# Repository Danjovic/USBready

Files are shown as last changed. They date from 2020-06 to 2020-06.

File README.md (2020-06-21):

# USBready
USB breadboard ready development board

Uses [USBaspLoader](https://www.obdev.at/products/vusb/usbasploader.html) as a bootloader. 

Precompiled .hex files available on 
[repository ](/Firmware/Bootloader/USBaspLoader.2012-12-08/hexfiles/)

PCB shared at [OSHPark](https://oshpark.com/shared_projects/ElsYFBDc)

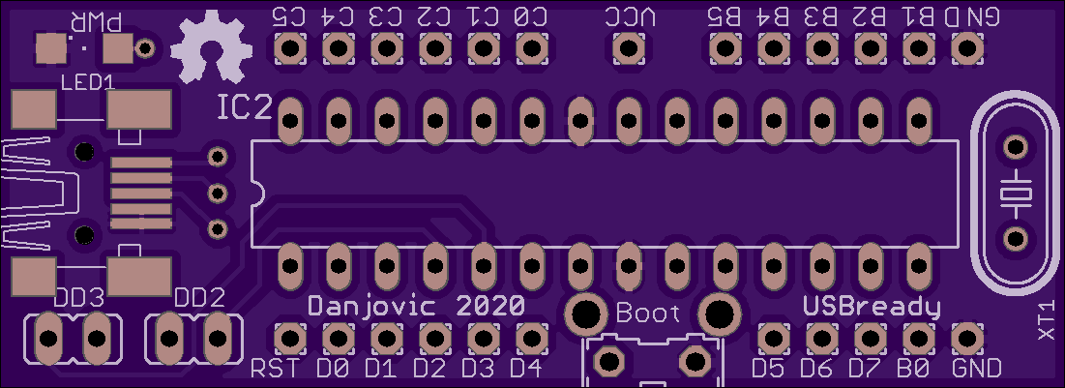
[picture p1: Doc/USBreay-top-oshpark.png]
PCB Preview


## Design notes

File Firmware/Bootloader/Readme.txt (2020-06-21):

This is the README file for USBaspLoader.

USBaspLoader is a USB boot loader for AVR microcontrollers. It can be used on
all AVRs with at least 2 kB of boot loader section, e.g. the popular ATMega8.
The firmware is flashed into the upper 2 kB of the flash memory and takes
control immediately after reset. If a certain hardware condition is met
(this condition can be configured, e.g. a jumper), the boot loader waits for
data on the USB interface and loads it into the remaining part of the flash
memory. If the condition is not met, control is passed to the loaded firmware.

This boot loader is similar to Thomas Fischl's avrusbboot and our own
bootloadHID, but it requires no separate command line tool to upload the data.
USBaspLoader emulates Thomas Fischl's USBasp programmer instead. You can thus
use AVRDUDE to upload flash memory data (and if the option is enabled) EEPROM
data.

Since USBaspLoader cooperates with AVRDUDE, it can be used in conjunction with
the Arduino software to upload flash memory data.

FILES IN THE DISTRIBUTION
=========================
Readme.txt ........ The file you are currently reading.
firmware .......... Source code of the controller firmware.
firmware/usbdrv ... USB driver -- See Readme.txt in that directory for info
License.txt ....... Public license (GPL2) for all contents of this project.
Changelog.txt ..... Logfile documenting changes in soft-, firm- and hardware.

BUILDING AND INSTALLING
=======================
This project can be built on Unix (Linux, FreeBSD or Mac OS X) or Windows.

For all platforms, you must first describe your hardware in the file
"firmware/bootloaderconfig.h". See the documentation in the example provided
with this distribution for details. Then edit "firmware/Makefile" to reflect
the target device, the device's boot loader address and fuse bit values.

Building on Windows:
You need WinAVR for the firmware, see http://winavr.sourceforge.net/.
To build the firmware with WinAVR, change into the "firmware" directory,
check whether you need to edit the "Makefile" (e.g. change device settings,
programmer hardware, clock rate etc.) or bootloaderconfig.h and type "make"
to compile the source code. Before you upload the code to the device with
"make flash", you should set the fuses with "make fuse". To protect the boot
loader from overwriting itself, set the lock bits with "make lock" after
uploading the firmware.

Building on Unix (Linux, FreeBSD and Mac):
You need the GNU toolchain and avr-libc for the firmware. See
    http://www.nongnu.org/avr-libc/user-manual/install_tools.html
for a good description on how to install the GNU compiler toolchain and
avr-libc on Unix. For Mac OS X, we provide a read-made package, see
    http://www.obdev.at/avrmacpack/

To build the firmware, change to the "firmware" directory, edit "Makefile"
and bootloaderconfig.h as described in the Windows paragraph above and type
"make" to compile the source code. Before you upload the code to the device
with "make flash", you should set the fuses with "make fuse". Then protect the
boot loader firmware with "make lock".

WORKING WITH THE BOOT LOADER
============================
The boot loader is quite easy to use. Set the jumper (or whatever condition
you have configured) for boot loading on the target hardware, connect it to
the host computer and (if not bus powered) issue a Reset on the AVR.

You can now flash the device with AVRDUDE through a "virtual" USBasp
programmer.

USING THE USB DRIVER FOR YOUR OWN PROJECTS
==========================================
This project is not intended as a reference implementation. If you want to
use AVR-USB in your own projects, please see
   * PowerSwitch for the most basic example,
   * Automator for an HID example or
   * AVR-Doper for a very complex example on how to simulate a serial
     interface (virtual COM port).
All these projects can be downloaded from http://www.obdev.at/avrusb/

ABOUT THE LICENSE
=================
It is our intention to make our USB driver and this demo application
available to everyone. Moreover, we want to make a broad range of USB
projects and ideas for USB devices available to the general public. We
therefore want that all projects built with our USB driver are published
under an Open Source license. Our license for the USB driver and demo code is
the GNU General Public License Version 2 (GPL2). See the file "License.txt"
for details.

If you don't want to publish your source code under the GPL2, you can simply
pay money for AVR-USB. As an additional benefit you get USB PIDs for free,
licensed exclusively to you. See the file "CommercialLicense.txt" in the usbdrv
directory for details.

MORE INFORMATION
================
For more information about Objective Development's firmware-only USB driver
for Atmel's AVR microcontrollers please visit the URL

    http://www.obdev.at/products/avrusb/

A technical documentation of the driver's interface can be found in the
file "firmware/usbdrv/usbdrv.h".

--
(c) 2008 by OBJECTIVE DEVELOPMENT Software GmbH.
http://www.obdev.at/

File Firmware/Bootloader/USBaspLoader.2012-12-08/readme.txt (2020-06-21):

AVeRCADE Bootloader Instructions

1: Select correct firmware for your processor and crystal frequency.

2: Burn the firmware (see notes)

3: Burn the fuses:
   
   a. ATMEGA8      Low Fuse = 0x9F   High Fuse = 0xC0  
   b. ATMEGA328p   Low Fuse = 0xF7   High Fuse = 0xDA  Ext Fuse = 0x03

Notes: 
The bootloader shall be burn in the microcontroller before soldering on the board.
Alternatively it is possible to solder a header on the board for programming with USBAsp or another tool of your choice. The connections are:

     ISP Signal   AVeRCADE Pin
	SCK           B3
	MISO          B4
	MOSI          B5 
	GND           GND
	RST        boot jumper
	+Vcc       Anode ot LED

If you program the fuses incorrectly the microcontroller may stop responding to ISP commands and shall be erased by HSP programming or another tool like Fuse Doctor.

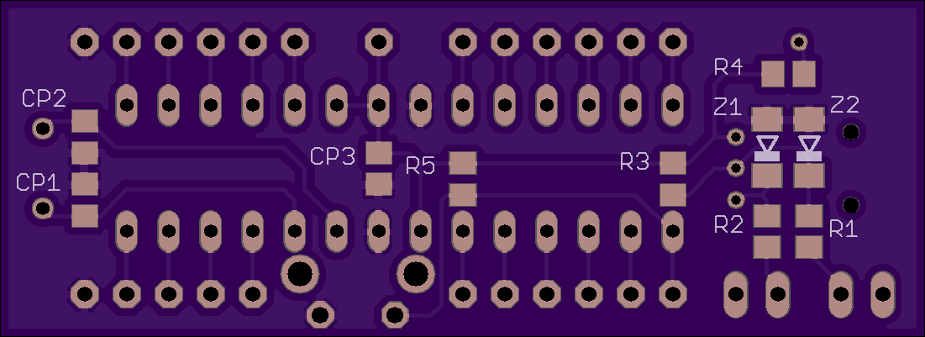
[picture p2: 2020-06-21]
Doc/USBreay-bottom-oshpark.png

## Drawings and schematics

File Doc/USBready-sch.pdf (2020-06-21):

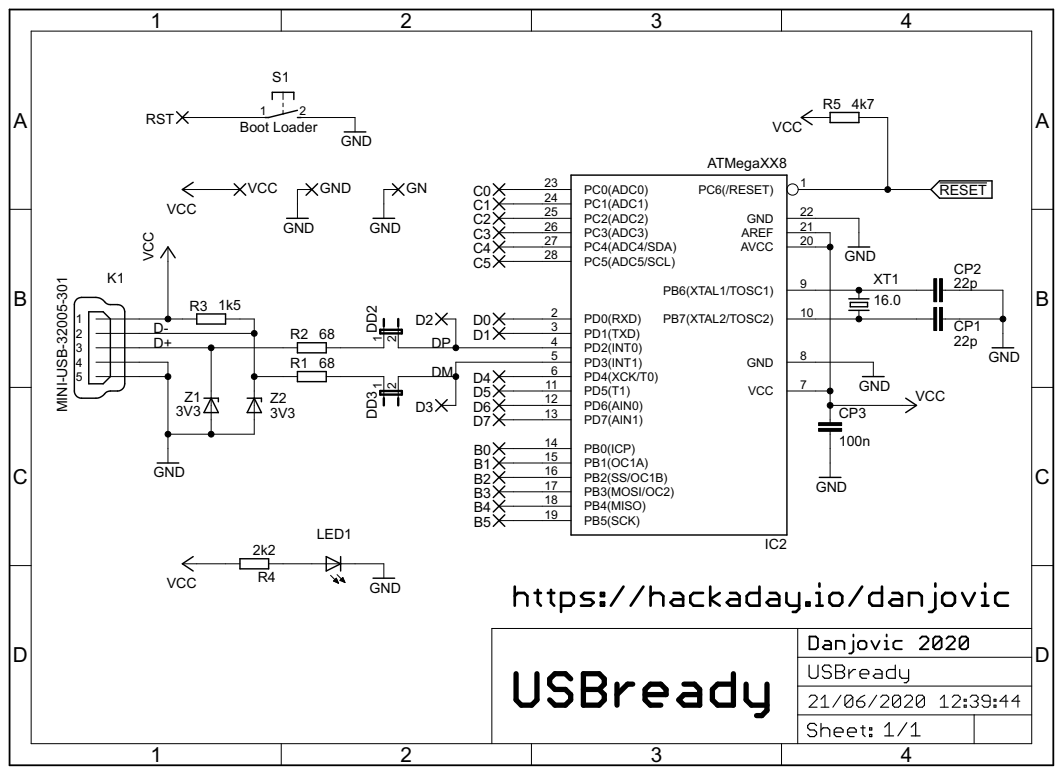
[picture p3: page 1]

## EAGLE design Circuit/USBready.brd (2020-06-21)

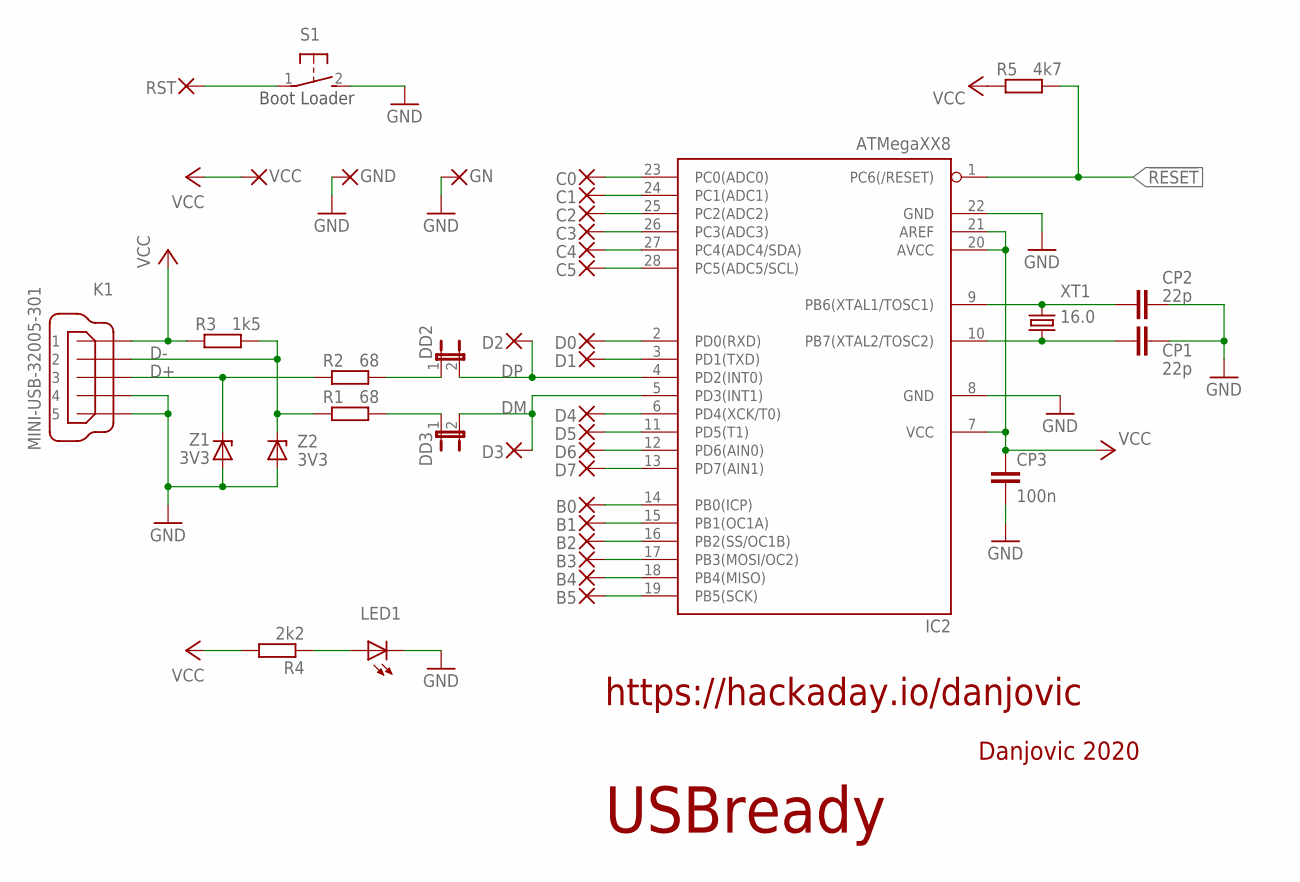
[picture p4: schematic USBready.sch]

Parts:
B0, B1, B2, B3, B4, B5: WIREPAD1,6/0,9; 1,6/0,9
C0, C1, C2, C3, C4, C5: WIREPAD1,6/0,9; 1,6/0,9
CP1, CP2: 22p; C0805
CP3: 100n; C0805
D0, D1, D2, D3, D4, D5, D6, D7: WIREPAD1,6/0,9; 1,6/0,9
DD2, DD3: JP1E; JP1
GN: WIREPAD1,6/0,9; 1,6/0,9
GND: WIREPAD1,6/0,9; 1,6/0,9
IC2: ATMegaXX8; DIL28-3
K1: MINI-USB-32005-301; 32005-301
LED1: LEDSML1206; SML1206
R1, R2: 68; M0805
R3: 1k5; R0805
R4: 2k2; R0805
R5: 4k7; M0805
RST: WIREPAD1,6/0,9; 1,6/0,9
S1: 31-XX; B3F-31XX
VCC: WIREPAD1,6/0,9; 1,6/0,9
XT1: 16.0; HC49/S
Z1, Z2: 3V3; SOD80C

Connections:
!RESET: IC2.1 (PC6(/RESET)), R5.2, RST.1, S1.1
AN2: C2.1, IC2.25 (PC2(ADC2))
AN3: C3.1, IC2.26 (PC3(ADC3))
D+: K1.3, R2.1, Z1.C
D-: K1.2, R1.1, R3.2, Z2.C
DM: D3.1, DD3.2, IC2.5 (PD3(INT1))
DP: D2.1, DD2.2, IC2.4 (PD2(INT0))
GND: CP1.2, CP2.2, CP3.2, GN.1, GND.1, IC2.8 (GND), IC2.22 (GND), K1.4, K1.5, LED1.C, S1.2 (S), Z1.A, Z2.A
unnamed: D0.1, IC2.2 (PD0(RXD))
unnamed: D4.1, IC2.6 (PD4(XCK/T0))
unnamed: C1.1, IC2.24 (PC1(ADC1))
unnamed: C0.1, IC2.23 (PC0(ADC0))
unnamed: C4.1, IC2.27 (PC4(ADC4/SDA))
unnamed: C5.1, IC2.28 (PC5(ADC5/SCL))
unnamed: D1.1, IC2.3 (PD1(TXD))
unnamed: D5.1, IC2.11 (PD5(T1))
unnamed: D6.1, IC2.12 (PD6(AIN0))
unnamed: D7.1, IC2.13 (PD7(AIN1))
unnamed: LED1.A, R4.1
unnamed: B0.1, IC2.14 (PB0(ICP))
unnamed: B2.1, IC2.16 (PB2(SS/OC1B))
unnamed: B1.1, IC2.15 (PB1(OC1A))
unnamed: B5.1, IC2.19 (PB5(SCK))
unnamed: B4.1, IC2.18 (PB4(MISO))
unnamed: B3.1, IC2.17 (PB3(MOSI/OC2))
unnamed: DD2.1, R2.2
unnamed: DD3.1, R1.2
VCC: CP3.1, IC2.7 (VCC), IC2.20 (AVCC), IC2.21 (AREF), K1.1, R3.1, R4.2, R5.1, VCC.1
X1: CP2.1, IC2.9 (PB6(XTAL1/TOSC1)), XT1.2
X2: CP1.1, IC2.10 (PB7(XTAL2/TOSC2)), XT1.1

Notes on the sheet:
Boot Loader
Danjovic 2020
USBready
https://hackaday.io/danjovic

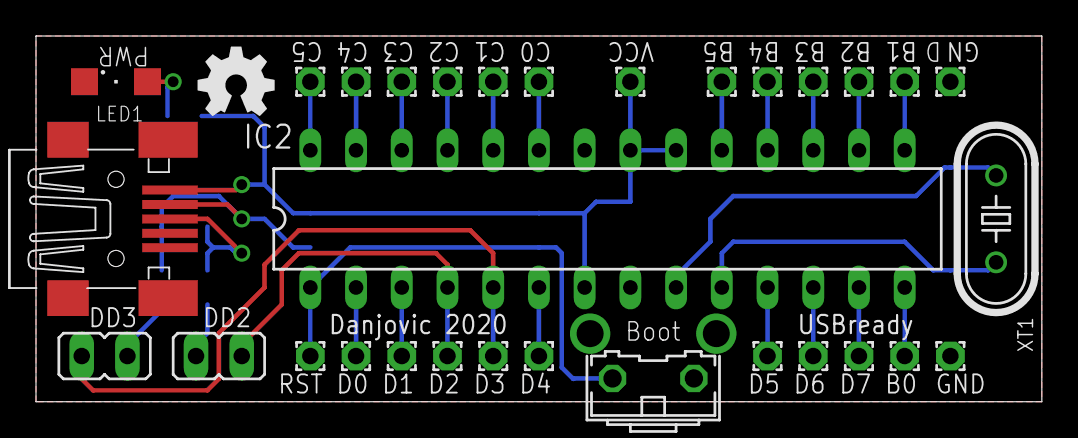
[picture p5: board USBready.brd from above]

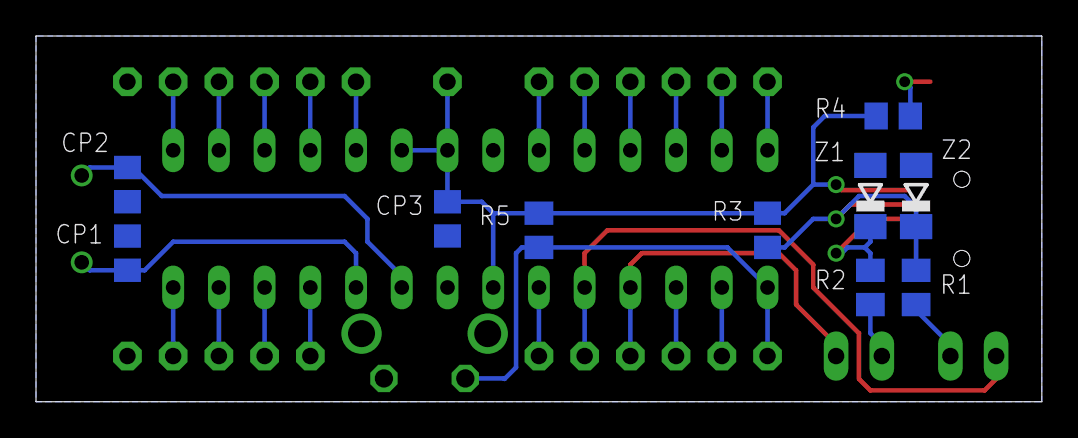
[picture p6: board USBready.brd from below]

Board: 2 copper layers, 55.9 x 20.3 mm, 41 parts (10 on the bottom side), 30 nets.

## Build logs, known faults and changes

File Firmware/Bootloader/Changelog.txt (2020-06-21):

This file documents changes in the firmware of USBaspLoader.
New entries are always appended to the end of the file. Scroll down to the
bottom to see the most recent changes.

* Release 2008-01-21

- Use most recent driver.

* Release 2008-02-05

- Disable USB interrupt before we jump to loaded application. Applications
  which don't use INT0 would otherwise crash when they perform sei().
- Revert all config changes to RESET condition before we jump to application.
- Code size optimizations suggested by Alexander Neumann.

* Release 2009-03-20

- Added some optimizations so that the boot loader can be used with gcc 4.3.
- Added fuse options (as comments) for ATMega328p to Makefile and include in
  precompiled hex files.
- Updated usbconfig.h to the latest template (mostly new comments).

* Release 2010-07-27

- Updated to latest driver, using gcc 4.6.2. This saves a couple of bytes, so
  that we can include EEPROM support in more configurations.

* Release 2012-12-08

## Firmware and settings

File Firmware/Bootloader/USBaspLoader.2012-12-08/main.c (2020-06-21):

/* Name: main.c
 * Project: USBaspLoader
 * Author: Christian Starkjohann
 * Creation Date: 2007-12-08
 * Tabsize: 4
 * Copyright: (c) 2007 by OBJECTIVE DEVELOPMENT Software GmbH
 * License: GNU GPL v2 (see License.txt)
 * This Revision: $Id$
 */

#include <avr/io.h>
#include <avr/interrupt.h>
#include <avr/pgmspace.h>
#include <avr/wdt.h>
#include <avr/boot.h>
#include <avr/eeprom.h>
#include <util/delay.h>
#include <string.h>

static void leaveBootloader() __attribute__((__noreturn__));

#include "bootloaderconfig.h"
#include "usbdrv/usbdrv.c"

/* ------------------------------------------------------------------------ */

/* Request constants used by USBasp */
#define USBASP_FUNC_CONNECT         1
#define USBASP_FUNC_DISCONNECT      2
#define USBASP_FUNC_TRANSMIT        3
#define USBASP_FUNC_READFLASH       4
#define USBASP_FUNC_ENABLEPROG      5
#define USBASP_FUNC_WRITEFLASH      6
#define USBASP_FUNC_READEEPROM      7
#define USBASP_FUNC_WRITEEEPROM     8
#define USBASP_FUNC_SETLONGADDRESS  9

/* ------------------------------------------------------------------------ */

#ifndef ulong
#   define ulong    unsigned long
#endif
#ifndef uint
#   define uint     unsigned int
#endif

/* defaults if not in config file: */
#ifndef HAVE_EEPROM_PAGED_ACCESS
#   define HAVE_EEPROM_PAGED_ACCESS 0
#endif
#ifndef HAVE_EEPROM_BYTE_ACCESS
#   define HAVE_EEPROM_BYTE_ACCESS  0
#endif
#ifndef BOOTLOADER_CAN_EXIT
#   define  BOOTLOADER_CAN_EXIT     0
#endif

/* allow compatibility with avrusbboot's bootloaderconfig.h: */
#ifdef BOOTLOADER_INIT
#   define bootLoaderInit()         BOOTLOADER_INIT
#   define bootLoaderExit()
#endif
#ifdef BOOTLOADER_CONDITION
#   define bootLoaderCondition()    BOOTLOADER_CONDITION
#endif

/* device compatibility: */
#ifndef GICR    /* ATMega*8 don't have GICR, use MCUCR instead */
#   define GICR     MCUCR
#endif

/* ------------------------------------------------------------------------ */

#if (FLASHEND) > 0xffff /* we need long addressing */
#   define CURRENT_ADDRESS  currentAddress.l
#   define addr_t           ulong
#else
#   define CURRENT_ADDRESS  currentAddress.w[0]
#   define addr_t           uint
#endif

typedef union longConverter{
    addr_t  l;
    uint    w[sizeof(addr_t)/2];
    uchar   b[sizeof(addr_t)];
}longConverter_t;

static uchar            requestBootLoaderExit;
static longConverter_t  currentAddress; /* in bytes */
static uchar            bytesRemaining;
static uchar            isLastPage;
#if HAVE_EEPROM_PAGED_ACCESS
static uchar            currentRequest;
#else
static const uchar      currentRequest = 0;
#endif

static const uchar  signatureBytes[4] = {
#ifdef SIGNATURE_BYTES
    SIGNATURE_BYTES
#elif defined (__AVR_ATmega8__) || defined (__AVR_ATmega8HVA__)
    0x1e, 0x93, 0x07, 0
#elif defined (__AVR_ATmega48__) || defined (__AVR_ATmega48P__)
    0x1e, 0x92, 0x05, 0
#elif defined (__AVR_ATmega88__) || defined (__AVR_ATmega88P__)
    0x1e, 0x93, 0x0a, 0
#elif defined (__AVR_ATmega168__) || defined (__AVR_ATmega168P__)
    0x1e, 0x94, 0x06, 0
#elif defined (__AVR_ATmega328P__)
    0x1e, 0x95, 0x0f, 0
#else
#   error "Device signature is not known, please edit main.c!"
#endif
};

/* ------------------------------------------------------------------------ */

static void (*nullVector)(void) __attribute__((__noreturn__));

static void leaveBootloader()
{
    DBG1(0x01, 0, 0);
    bootLoaderExit();
    cli();
    USB_INTR_ENABLE = 0;
    USB_INTR_CFG = 0;       /* also reset config bits */
    GICR = (1 << IVCE);     /* enable change of interrupt vectors */
    GICR = (0 << IVSEL);    /* move interrupts to application flash section */
/* We must go through a global function pointer variable instead of writing
 *  ((void (*)(void))0)();
 * because the compiler optimizes a constant 0 to "rcall 0" which is not
 * handled correctly by the assembler.
 */
    nullVector();
}

/* ------------------------------------------------------------------------ */

uchar   usbFunctionSetup(uchar data[8])
{
usbRequest_t    *rq = (void *)data;
uchar           len = 0;
static uchar    replyBuffer[4];

    usbMsgPtr = (usbMsgPtr_t)replyBuffer;
    if(rq->bRequest == USBASP_FUNC_TRANSMIT){   /* emulate parts of ISP protocol */
        uchar rval = 0;
        usbWord_t address;
        address.bytes[1] = rq->wValue.bytes[1];
        address.bytes[0] = rq->wIndex.bytes[0];
        if(rq->wValue.bytes[0] == 0x30){        /* read signature */
            rval = rq->wIndex.bytes[0] & 3;
            rval = signatureBytes[rval];
#if HAVE_EEPROM_BYTE_ACCESS
        }else if(rq->wValue.bytes[0] == 0xa0){  /* read EEPROM byte */
            rval = eeprom_read_byte((void *)address.word);
        }else if(rq->wValue.bytes[0] == 0xc0){  /* write EEPROM byte */
            eeprom_write_byte((void *)address.word, rq->wIndex.bytes[1]);
#endif
#if HAVE_CHIP_ERASE
        }else if(rq->wValue.bytes[0] == 0xac && rq->wValue.bytes[1] == 0x80){  /* chip erase */
            addr_t addr;
            for(addr = 0; addr < FLASHEND + 1 - 2048; addr += SPM_PAGESIZE) {
                /* wait and erase page */
                DBG1(0x33, 0, 0);
#   ifndef NO_FLASH_WRITE
                boot_spm_busy_wait();
                cli();
                boot_page_erase(addr);
                sei();
#   endif
            }
#endif
        }else{
            /* ignore all others, return default value == 0 */
        }
        replyBuffer[3] = rval;
        len = 4;
    }else if(rq->bRequest == USBASP_FUNC_ENABLEPROG){
        /* replyBuffer[0] = 0; is never touched and thus always 0 which means success */
        len = 1;
    }else if(rq->bRequest >= USBASP_FUNC_READFLASH && rq->bRequest <= USBASP_FUNC_SETLONGADDRESS){
        currentAddress.w[0] = rq->wValue.word;
        if(rq->bRequest == USBASP_FUNC_SETLONGADDRESS){
#if (FLASHEND) > 0xffff
            currentAddress.w[1] = rq->wIndex.word;
#endif
        }else{
            bytesRemaining = rq->wLength.bytes[0];
            /* if(rq->bRequest == USBASP_FUNC_WRITEFLASH) only evaluated during writeFlash anyway */
            isLastPage = rq->wIndex.bytes[1] & 0x02;
#if HAVE_EEPROM_PAGED_ACCESS
            currentRequest = rq->bRequest;
#endif
            len = 0xff; /* hand over to usbFunctionRead() / usbFunctionWrite() */
        }
#if BOOTLOADER_CAN_EXIT
    }else if(rq->bRequest == USBASP_FUNC_DISCONNECT){
        requestBootLoaderExit = 1;      /* allow proper shutdown/close of connection */
#endif
    }else{
        /* ignore: USBASP_FUNC_CONNECT */
    }
    return len;
}

uchar usbFunctionWrite(uchar *data, uchar len)
{
uchar   isLast;

    DBG1(0x31, (void *)&currentAddress.l, 4);
    if(len > bytesRemaining)
        len = bytesRemaining;
    bytesRemaining -= len;
    isLast = bytesRemaining == 0;
    if(currentRequest >= USBASP_FUNC_READEEPROM){
        uchar i;
        for(i = 0; i < len; i++){
            eeprom_write_byte((void *)(currentAddress.w[0]++), *data++);
        }
    }else{
        uchar i;
        for(i = 0; i < len;){
#if !HAVE_CHIP_ERASE
            if((currentAddress.w[0] & (SPM_PAGESIZE - 1)) == 0){    /* if page start: erase */
                DBG1(0x33, 0, 0);
#   ifndef NO_FLASH_WRITE
                cli();
                boot_page_erase(CURRENT_ADDRESS);   /* erase page */
                sei();
                boot_spm_busy_wait();               /* wait until page is erased */
#   endif
            }
#endif
            i += 2;
            DBG1(0x32, 0, 0);
            cli();
            boot_page_fill(CURRENT_ADDRESS, *(short *)data);
            sei();
            CURRENT_ADDRESS += 2;
            data += 2;
            /* write page when we cross page boundary or we have the last partial page */
            if((currentAddress.w[0] & (SPM_PAGESIZE - 1)) == 0 || (isLast && i >= len && isLastPage)){
                DBG1(0x34, 0, 0);
#ifndef NO_FLASH_WRITE
                cli();
                boot_page_write(CURRENT_ADDRESS - 2);
                sei();
                boot_spm_busy_wait();
                cli();
                boot_rww_enable();
                sei();
#endif
            }
        }
        DBG1(0x35, (void *)&currentAddress.l, 4);
    }
    return isLast;
}

uchar usbFunctionRead(uchar *data, uchar len)
{
uchar   i;

    if(len > bytesRemaining)
        len = bytesRemaining;
    bytesRemaining -= len;
    for(i = 0; i < len; i++){
        if(currentRequest >= USBASP_FUNC_READEEPROM){
            *data = eeprom_read_byte((void *)currentAddress.w[0]);
        }else{
            *data = pgm_read_byte((void *)CURRENT_ADDRESS);
        }
        data++;
        CURRENT_ADDRESS++;
    }
    return len;
}

/* ------------------------------------------------------------------------ */

static void initForUsbConnectivity(void)
{
uchar   i = 0;

    usbInit();
    /* enforce USB re-enumerate: */
    usbDeviceDisconnect();  /* do this while interrupts are disabled */
    while(--i){         /* fake USB disconnect for > 250 ms */
        wdt_reset();
        _delay_ms(1);
    }
    usbDeviceConnect();
    sei();
}

int __attribute__((noreturn)) main(void)
{
    /* initialize  */
    wdt_disable();      /* main app may have enabled watchdog */
    bootLoaderInit();
    odDebugInit();
    DBG1(0x00, 0, 0);
#ifndef NO_FLASH_WRITE
    GICR = (1 << IVCE);  /* enable change of interrupt vectors */
    GICR = (1 << IVSEL); /* move interrupts to boot flash section */
#endif
    if(bootLoaderCondition()){
        uchar i = 0, j = 0;
        initForUsbConnectivity();
        do{
            usbPoll();
#if BOOTLOADER_CAN_EXIT
            if(requestBootLoaderExit){
                if(--i == 0){
                    if(--j == 0)
                        break;
                }
            }
#endif
        }while(bootLoaderCondition());  /* main event loop */
    }
    leaveBootloader();
}

/* ------------------------------------------------------------------------ */

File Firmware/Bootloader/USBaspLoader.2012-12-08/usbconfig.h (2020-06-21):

/* Name: usbconfig.h
 * Project: V-USB, virtual USB port for Atmel's(r) AVR(r) microcontrollers
 * Author: Christian Starkjohann
 * Creation Date: 2005-04-01
 * Tabsize: 4
 * Copyright: (c) 2005 by OBJECTIVE DEVELOPMENT Software GmbH
 * License: GNU GPL v2 (see License.txt), GNU GPL v3 or proprietary (CommercialLicense.txt)
 * This Revision: $Id$
 */

#ifndef __usbconfig_h_included__
#define __usbconfig_h_included__

/* YOU SHOULD NOT NEED TO MODIFY THIS FILE! All configurations are supposed
 * to go into bootloaderconfig.h!
 */

/* ---------------------------- Hardware Config ---------------------------- */

/* All the port and pin assignments, as well as the clock speed and CRC
   setting are now in bootloaderconfig.h: */

#include "bootloaderconfig.h"

/* --------------------------- Functional Range ---------------------------- */

#define USB_CFG_HAVE_INTRIN_ENDPOINT    0
/* Define this to 1 if you want to compile a version with two endpoints: The
 * default control endpoint 0 and an interrupt-in endpoint (any other endpoint
 * number).
 */
#define USB_CFG_HAVE_INTRIN_ENDPOINT3   0
/* Define this to 1 if you want to compile a version with three endpoints: The
 * default control endpoint 0, an interrupt-in endpoint 3 (or the number
 * configured below) and a catch-all default interrupt-in endpoint as above.
 * You must also define USB_CFG_HAVE_INTRIN_ENDPOINT to 1 for this feature.
 */
#define USB_CFG_EP3_NUMBER              3
/* If the so-called endpoint 3 is used, it can now be configured to any other
 * endpoint number (except 0) with this macro. Default if undefined is 3.
 */
/* #define USB_INITIAL_DATATOKEN           USBPID_DATA1 */
/* The above macro defines the startup condition for data toggling on the
 * interrupt/bulk endpoints 1 and 3. Defaults to USBPID_DATA1.
 * Since the token is toggled BEFORE sending any data, the first packet is
 * sent with the oposite value of this configuration!
 */
#define USB_CFG_IMPLEMENT_HALT          0
/* Define this to 1 if you also want to implement the ENDPOINT_HALT feature
 * for endpoint 1 (interrupt endpoint). Although you may not need this feature,
 * it is required by the standard. We have made it a config option because it
 * bloats the code considerably.
 */
#define USB_CFG_SUPPRESS_INTR_CODE      0
/* Define this to 1 if you want to declare interrupt-in endpoints, but don't
 * want to send any data over them. If this macro is defined to 1, functions
 * usbSetInterrupt() and usbSetInterrupt3() are omitted. This is useful if
 * you need the interrupt-in endpoints in order to comply to an interface
 * (e.g. HID), but never want to send any data. This option saves a couple
 * of bytes in flash memory and the transmit buffers in RAM.
 */
#define USB_CFG_INTR_POLL_INTERVAL      10
/* If you compile a version with endpoint 1 (interrupt-in), this is the poll
 * interval. The value is in milliseconds and must not be less than 10 ms for
 * low speed devices.
 */
#ifndef USB_CFG_IS_SELF_POWERED // allow bootloaderconfig.h to override
#define USB_CFG_IS_SELF_POWERED         0
#endif
/* Define this to 1 if the device has its own power supply. Set it to 0 if the
 * device is powered from the USB bus.
 */
#ifndef USB_CFG_MAX_BUS_POWER   // allow bootloaderconfig.h to override
#define USB_CFG_MAX_BUS_POWER           100
#endif
/* Set this variable to the maximum USB bus power consumption of your device.
 * The value is in milliamperes. [It will be divided by two since USB
 * communicates power requirements in units of 2 mA.]
 */
#define USB_CFG_IMPLEMENT_FN_WRITE      1
/* Set this to 1 if you want usbFunctionWrite() to be called for control-out
 * transfers. Set it to 0 if you don't need it and want to save a couple of
 * bytes.
 */
#define USB_CFG_IMPLEMENT_FN_READ       1
/* Set this to 1 if you need to send control replies which are generated
 * "on the fly" when usbFunctionRead() is called. If you only want to send
 * data from a static buffer, set it to 0 and return the data from
 * usbFunctionSetup(). This saves a couple of bytes.
 */
#define USB_CFG_IMPLEMENT_FN_WRITEOUT   0
/* Define this to 1 if you want to use interrupt-out (or bulk out) endpoints.
 * You must implement the function usbFunctionWriteOut() which receives all
 * interrupt/bulk data sent to any endpoint other than 0. The endpoint number
 * can be found in 'usbRxToken'.
 */
#define USB_CFG_HAVE_FLOWCONTROL        0
/* Define this to 1 if you want flowcontrol over USB data. See the definition
 * of the macros usbDisableAllRequests() and usbEnableAllRequests() in
 * usbdrv.h.
 */
#define USB_CFG_DRIVER_FLASH_PAGE       0
/* If the device has more than 64 kBytes of flash, define this to the 64 k page
 * where the driver's constants (descriptors) are located. Or in other words:
 * Define this to 1 for boot loaders on the ATMega128.
 */
#define USB_CFG_LONG_TRANSFERS          0
/* Define this to 1 if you want to send/receive blocks of more than 254 bytes
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
